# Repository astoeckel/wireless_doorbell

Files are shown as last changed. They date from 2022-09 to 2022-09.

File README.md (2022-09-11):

# Wireless Doorbell
**A hopelessly overengineered wireless doorbell transmitter (and Raspberry Pi AVR prototyping HAT)**

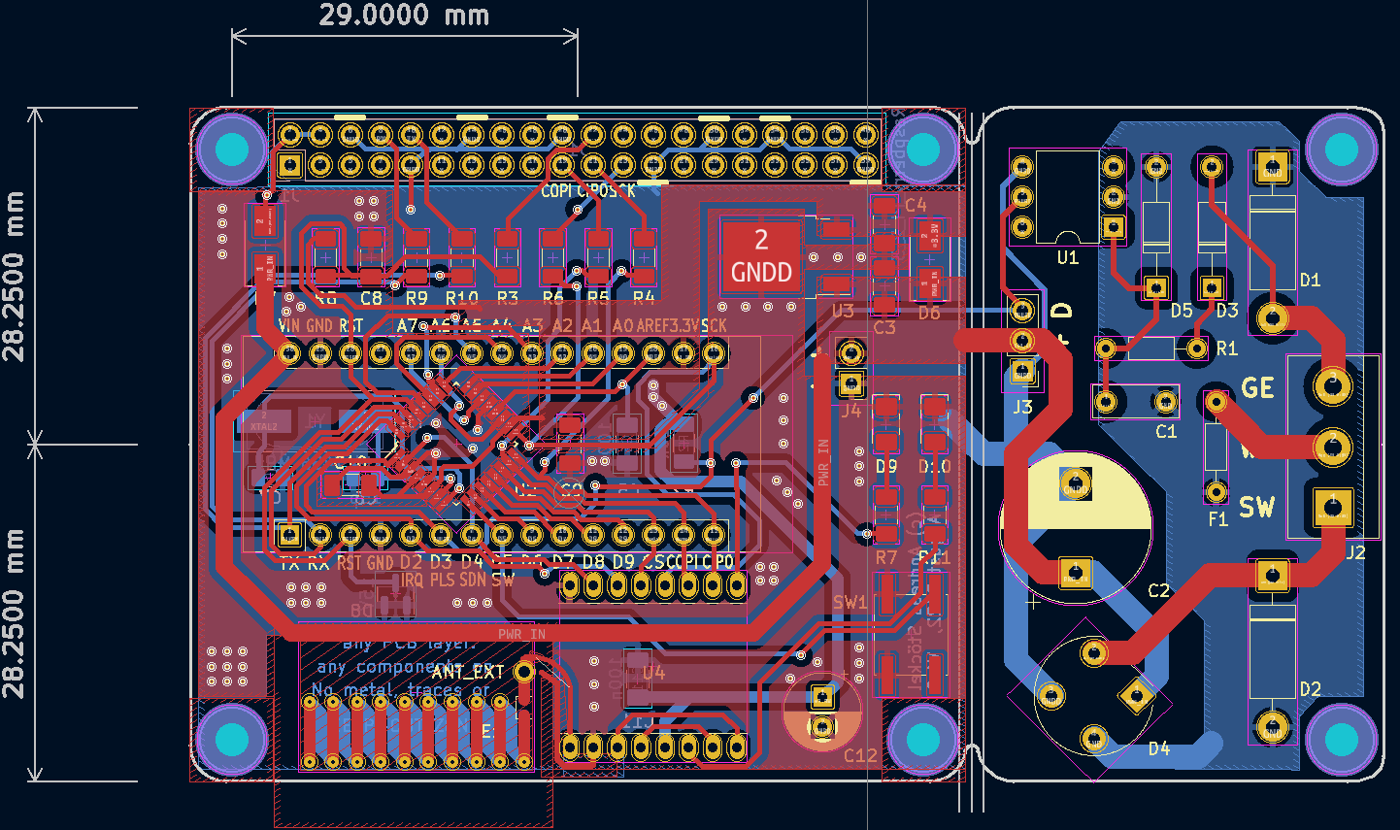
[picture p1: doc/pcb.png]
Screenshot of the PCB in KiCAD


> **Warning**  
> This project is provided as-is and likely not of use to anyone else; at least not without modifications. Note that:
> 1. The PCB (especially the AC supply) was designed for parts the author had lying around. Many of these parts may be obsolete.
> 2. This project solves a very niche problem.
> 3. The firmware uses plain-text wireless transmission without encryption or signatures. This is fine for the author's use case, where all an adversary can accomplish is to wirelessly ring the doorbell. A sneaky hacker could of course just press the doorbell button on the street to the same effect.
>
> **The author of this repository takes no responsibility for any damage resulting from using the electronic devices described here.**
> **You are responsible for making sure that operating these devices meets all relevant regulatory requirements in your region.**

This repository contains the PCB and firmware for a Si4463-based (on a HopeRF RFM26W module) wireless doorbell operating on the 433 MHz ISM band.
The Si4463 is controlled using an ATmega168 µC (the project requires about 6kiB of flash memory).

Doorbell button presses are transmitted wirelessly between two of these PCBs.
One of the PCBs serves as a Raspberry Pi HAT, where button press events are forwarded via UART to [OpenHAB](https://www.openhab.org/) (using [Serial Bridge and Serial Device](https://www.openhab.org/addons/bindings/serial/)).
In turn, OpenHAB has a rule that causes all SIP phones in the house to ring via [FemtoSIP](https://github.com/astoeckel/femtosip).

The left side of the PCB is a Raspberry Pi compatible AVR Microcontroller HAT (for the ATmega168/ATMega328 family) with Arduino-compatible pin headers and space for the HopeRF RFM26W module (note that this module seems to be obsolete).
The right side of the PCB is an low-voltage AC power supply with 50 Hz pulse extraction and is designed to be sawed off if not in use.

Since PCB prototyping services often produce at least 5-10 PCBs, the PCB was designed with some versatility in mind.
Correspondingly, the left side of the PCB has far more pin headers as necessary, and can be used as a general-purpose ATmega168/328 development board.
Specifically, the AVR can be programmed directly by the Raspberry Pi (no ISP programmer required) and can communicate via UART (the schematic suggests the use of a 14.7456 MHz crystal for stable high-speed communication).

## Overview

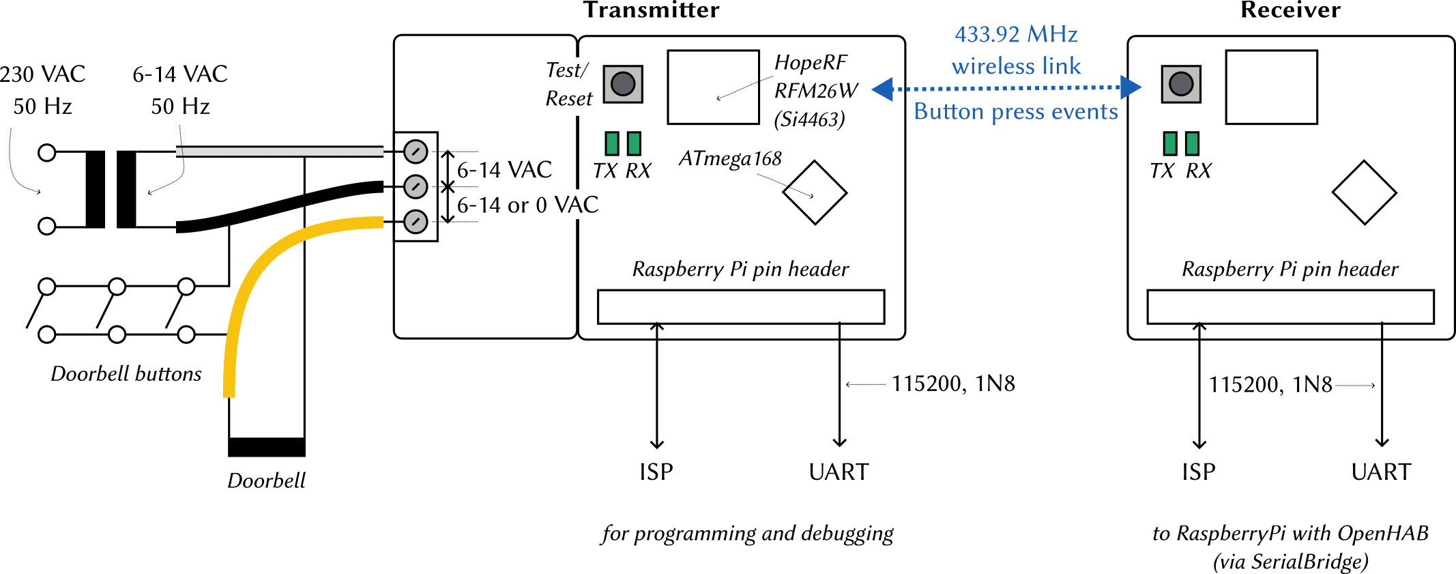
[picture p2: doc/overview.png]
Overview of the setup


The above diagram depicts how the PCB is intended to be used.
One instance of the PCB is directly powered by the low-voltage doorbell AC transformer; the other instance is powered by the 5V power supply of a Raspberry Pi.

Button presses are recognized by the doorbell button shorting out the yellow and black wires in the above diagram.
Correspondingly, the 50 Hz oscillations disappear on the yellow wire; this is recognized by the ATmega168 microcontroller which sends a few digital packets of the form
```
$DBG,<BUTTON PRESSED>,<SEQ>
```
to the receiver at a baud rate of 10kbps.
`<BUTTON PRESSED>` is set to `1` if the 50 Hz signal goes away; it is set to `0` once the signal reappears.
Every packet is repeated five times; with each repetition `<SEQ>` is incremented by one (starting from `0`).

## Schematics and Gerber files

* **Gerber files**  
  The Gerber files used for production can be found in the `gerber` folder (the author is not aware of any bugs on the PCB).
* **Schematic and KiCAD sources**  
  The KiCAD source files are in the `kicad` folder. A printout of the schematics in [PDF form](doc/schematics.pdf) can be found in the `doc` folder.

## Firmware

The firmware is located in the `code` folder.
It uses `avr-gcc` and `avr-libc`, as well as `avrdude` with the [linuxspi patches](https://github.com/kcuzner/avrdude).

It can be compiled and flashed using [meson](https://mesonbuild.com/) as follows:
```sh
cd code; mkdir -p build
meson setup --cross-file ../avr-unknown-gcc.txt ..
ninja
ninja flash  # Requires avrdude with linuxspi when flashing directly from the RPi
```

## Usage

The firmware automatically decides whether it acts as the receiver or transmitter depending on the presence of the 50 Hz pulse from the yellow wire in the above diagram.
Once a stable series of 50 Hz pulse are received, the device is in “transmitter” mode.

### Antenna
Note that the antenna on the board is designed for 868 MHz and does not have a large gain (close the solder bridge `J` on the board to activate the internal antenna).
In the final device, I'm using [this antenna](https://www.instructables.com/433-MHz-Coil-loaded-antenna/) ([PDF instructions by Ben Schueler](https://drive.google.com/file/d/1E9KPAPJrZRgGLOQqwd2-3-Px0MuSVreY/view)) soldered directly to the RFM26W module (the antenna is not connected to the PCB).

### Receiver

1. Connect UART RX/TX pins and 5V power (use a baud rate of 115200) to Raspberry Pi
2. The `RX` LED should be illuminated; the LED will blink rapidly if the receiver receives any data.
3. Incoming messages will be printed as a one-line JSON-encoded string to UART
4. Shortly pressing the SMD button on the board will send a `PING` request. If any board responds with a `PONG`, both the `RX` and `TX` LED will blink rapidly for two seconds. *Note:* The transmitter is usually in energy saving mode and will not respond. Wake the transmitter up by pressing the SMD button there.
5. Pressing the SMD button for at least 3 seconds will reset the µC on the board.

### Transmitter
1. Connect the three doorbell wires as indicated in the diagram above.
2. The `RX` led will blink once every second if the 50 Hz pulse has been recognized; the board will go to a 3-4mA power-save mode (this is to prevent the linear voltage regulator from becoming too hot).
3. If the 50 Hz signal goes away, the transmitter will send a message to the receiver as described above. The `TX` LED should blink rapidly.
4. Shortly pressing the SMD button will send a `PING` request and rapidly blink both LEDs if it receives a response. Furthermore, the transmitter will leave power-save mode for one minute; it can now respond with `PONG` to `PING` messages issued by the receiver.
5. Pressing the SMD button for 3 seconds will reset the µC on the board.

## License

Note that this project consists of both hardware and to a smaller portion of software. Both parts are made available under different licenses.

### Hardware schematics

    Copyright Andreas Stöckel 2022.
    
    This documentation describes Open Hardware and is licensed under the
    CERN OHL v. 1.2. You may redistribute and modify this documentation under
    the terms of the CERN OHL v.1.2. (http://ohwr.org/cernohl). This
    documentation is distributed WITHOUT ANY EXPRESS OR IMPLIED WARRANTY,
    INCLUDING OF MERCHANTABILITY, SATISFACTORY QUALITY AND FITNESS FOR A
    PARTICULAR PURPOSE. Please see the CERN OHL v.1.2 for applicable conditions.

### Software (AVR firmware and host programs)

    This program is free software: you can redistribute it and/or modify
    it under the terms of the GNU General Public License as published by
    the Free Software Foundation, either version 3 of the License, or
    (at your option) any later version.
    
    This program is distributed in the hope that it will be useful,
    but WITHOUT ANY WARRANTY; without even the implied warranty of
    MERCHANTABILITY or FITNESS FOR A PARTICULAR PURPOSE.  See the
    GNU General Public License for more details.
    
    You should have received a copy of the GNU General Public License
    along with this program.  If not, see <http://www.gnu.org/licenses/>.

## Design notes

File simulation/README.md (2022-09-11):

This directory contains some LTSpice simulations of different prototypes for the 14V AC power supply.
The final version in the `kicad` folder uses a simple bridge rectifier and a linear 3.3V regulator.

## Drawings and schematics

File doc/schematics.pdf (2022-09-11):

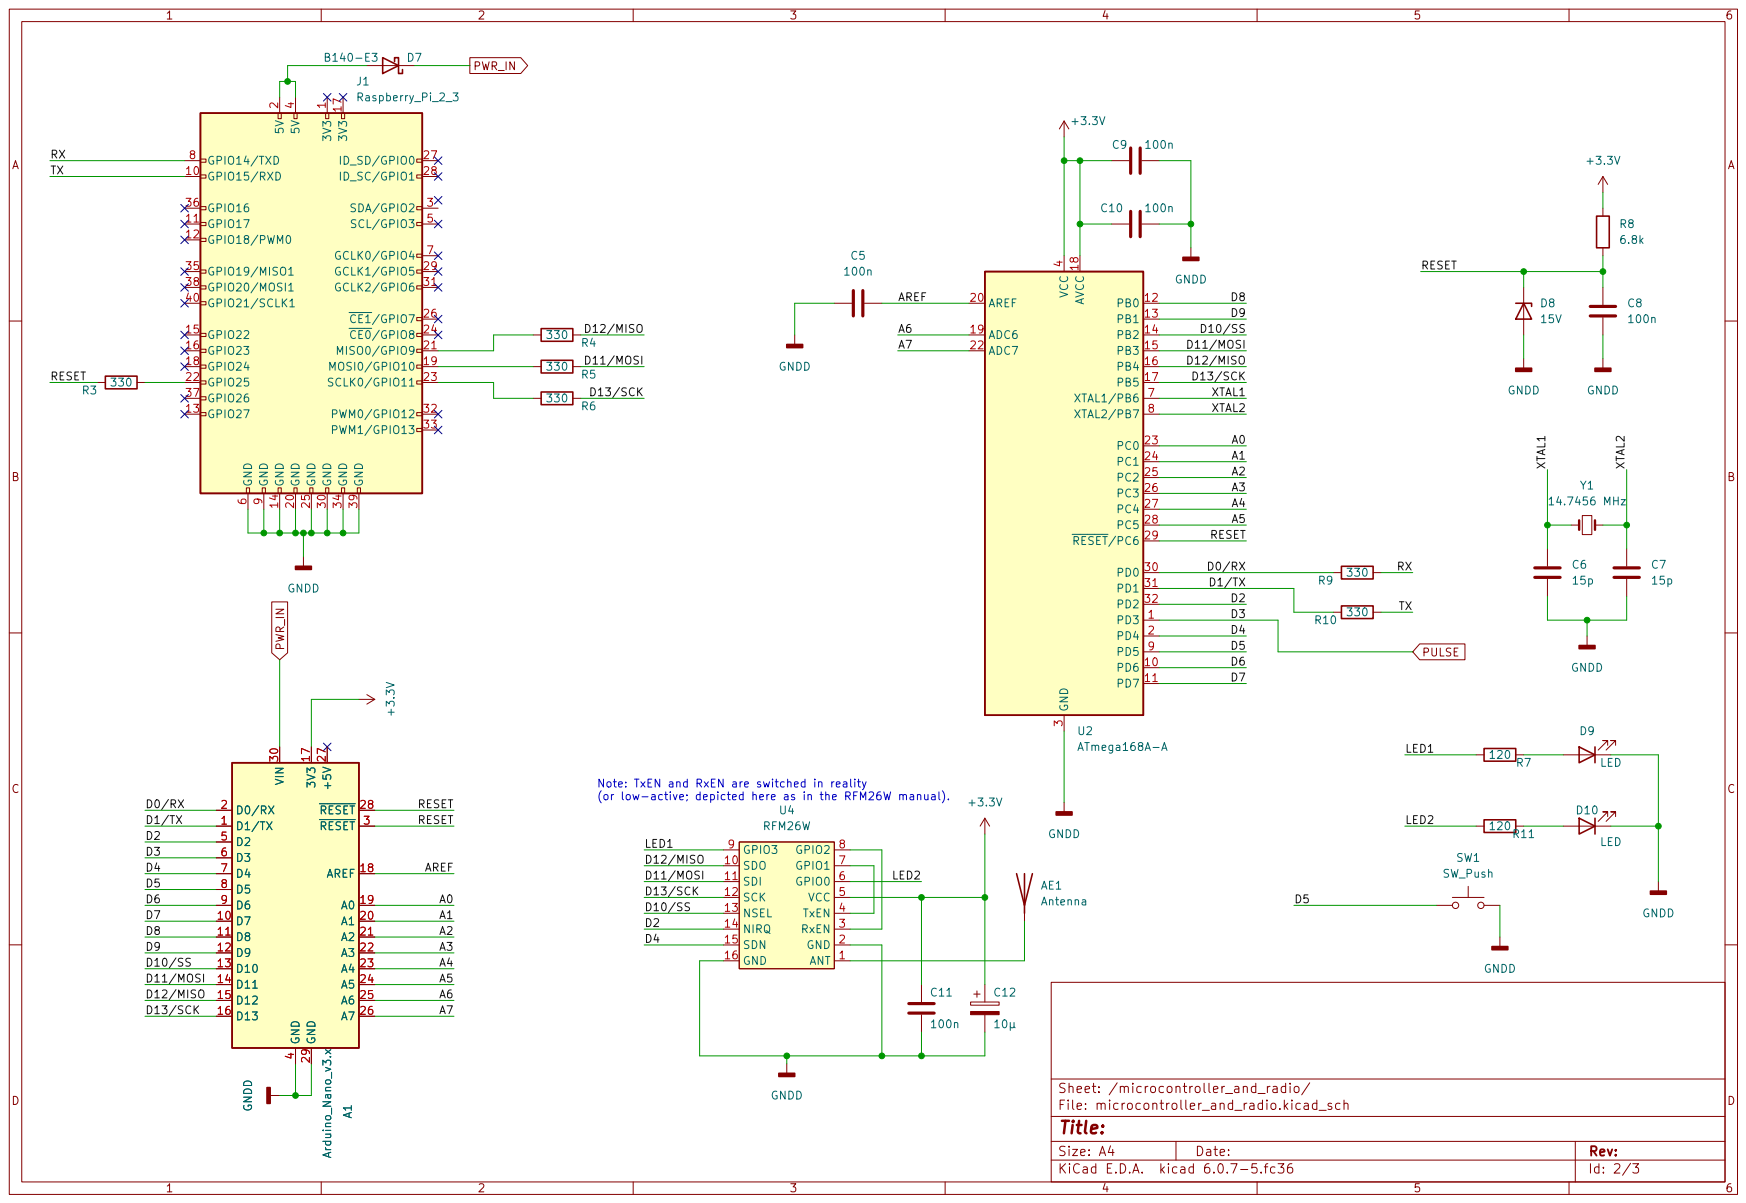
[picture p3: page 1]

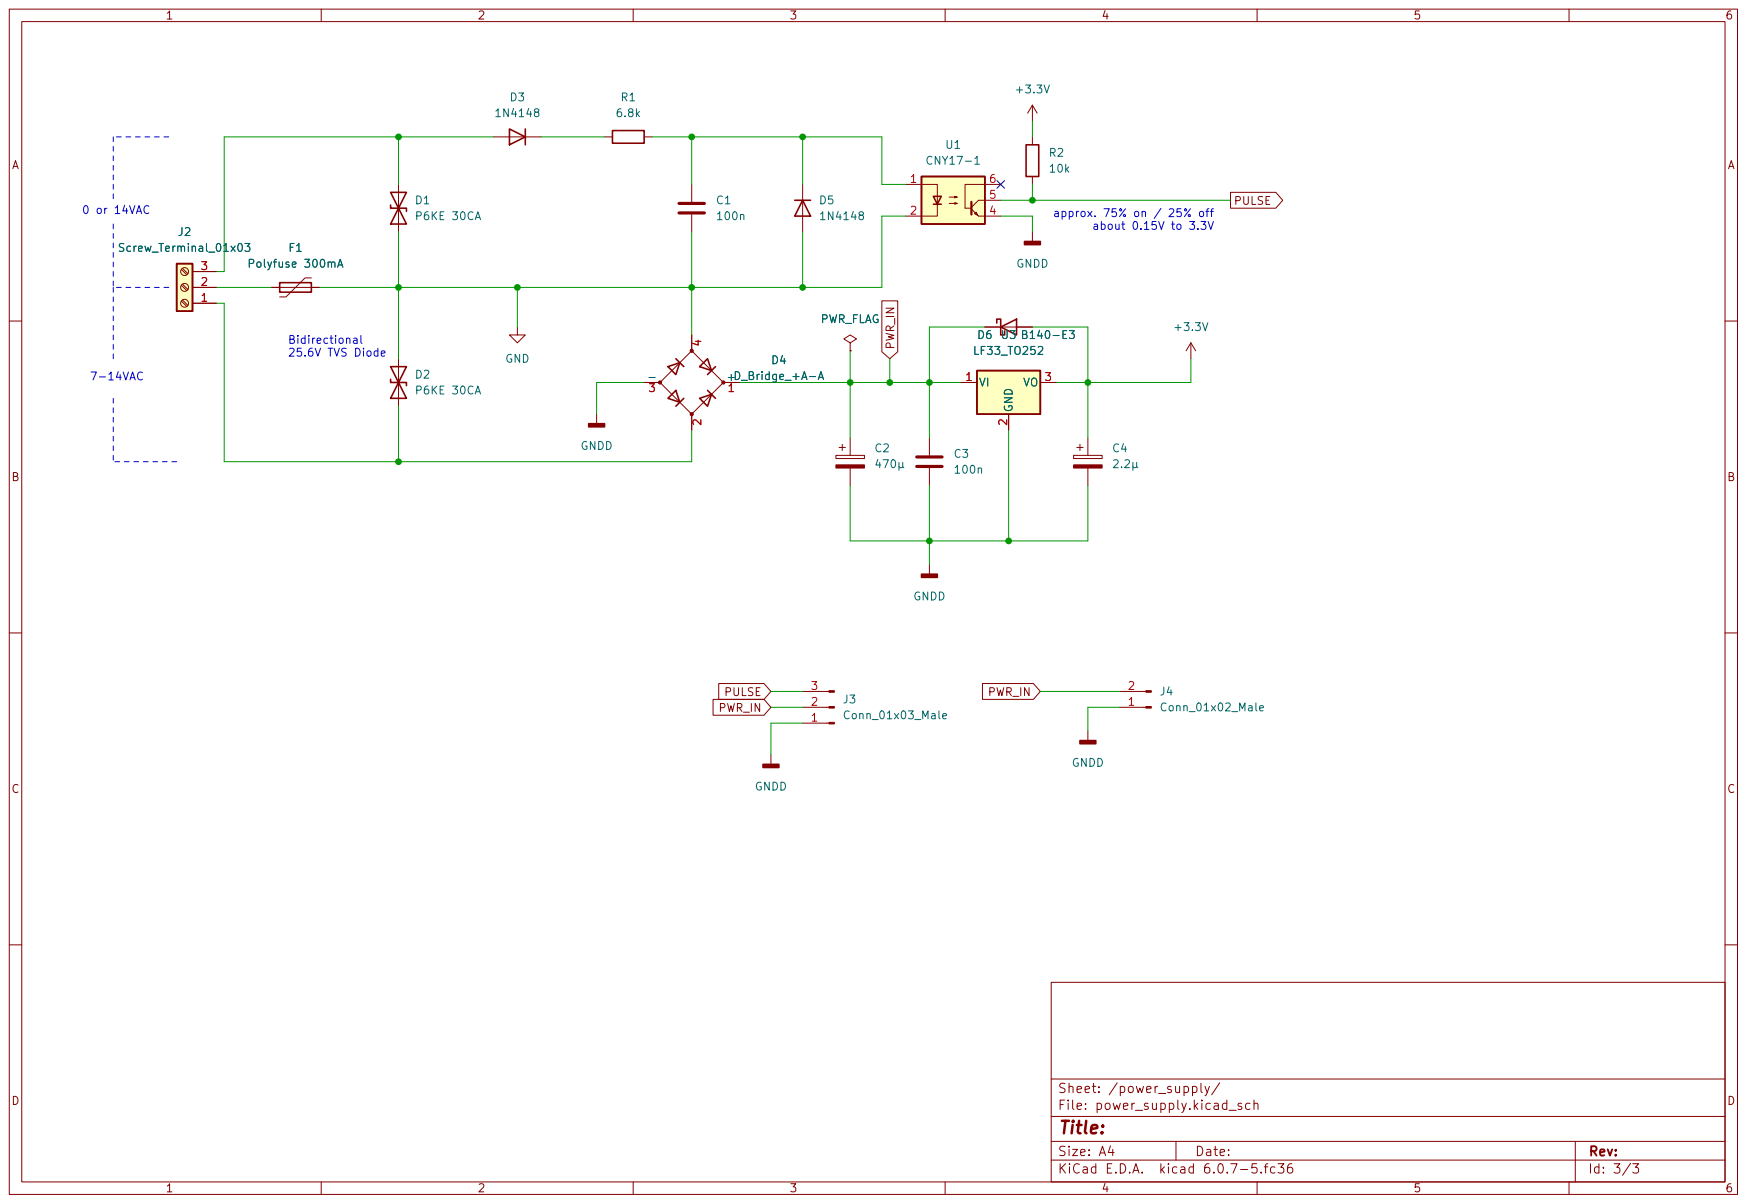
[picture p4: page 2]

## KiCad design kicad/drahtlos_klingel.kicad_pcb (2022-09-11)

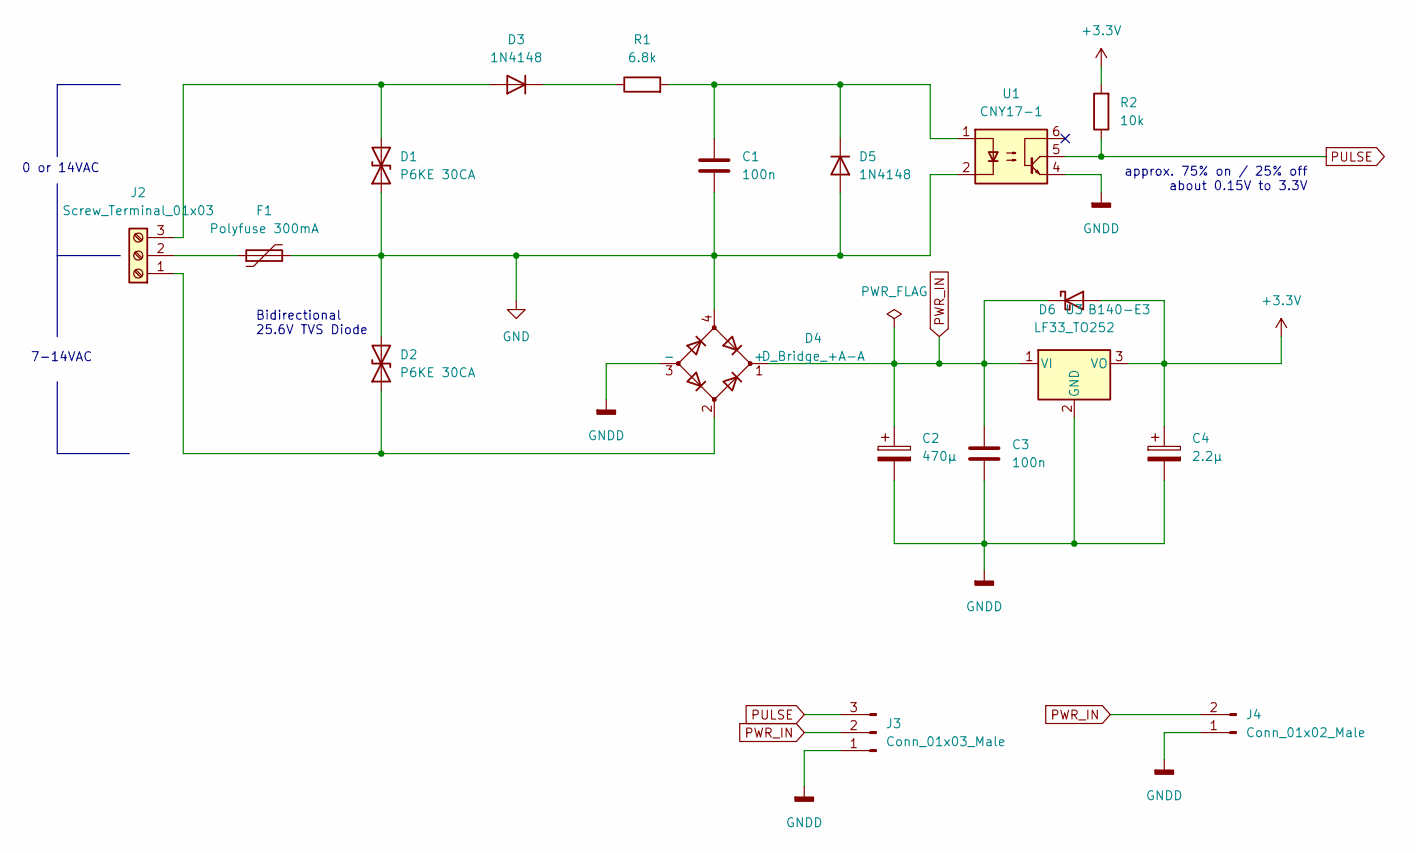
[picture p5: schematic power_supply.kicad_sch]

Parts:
C1: 100n; C_Rect_L7.0mm_W2.5mm_P5.00mm
C2: 470µ; CP_Radial_D12.5mm_P7.50mm
C3: 100n; C_1206_3216Metric_Pad1.33x1.80mm_HandSolder
C4: 2.2µ; C_1206_3216Metric_Pad1.33x1.80mm_HandSolder
D1, D2: P6KE 30CA; D_DO-15_P12.70mm_Horizontal
D3, D5: 1N4148; D_DO-35_SOD27_P10.16mm_Horizontal
D4: D_Bridge_+A-A; Diode_Bridge_Round_D9.8mm
D6: B140-E3; D_SMA
F1: Polyfuse 300mA; R_Axial_DIN0204_L3.6mm_D1.6mm_P7.62mm_Horizontal
J2: Screw_Terminal_01x03; TerminalBlock_bornier-3_P5.08mm
J3: Conn_01x03_Male; PinHeader_1x03_P2.54mm_Vertical
J4: Conn_01x02_Male; PinHeader_1x02_P2.54mm_Vertical
R1: 6.8k; R_Axial_DIN0204_L3.6mm_D1.6mm_P7.62mm_Horizontal
R2: 10k; R_1206_3216Metric_Pad1.30x1.75mm_HandSolder
U1: CNY17-1; DIP-6_W7.62mm
U3: LF33_TO252; TO-252-2

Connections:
+3.3V: C4.1, D6.2 (A), R2.2, U3.3 (VO); also elsewhere on the board
GND: C1.2, D1.1 (A1), D2.2 (A2), D4.4, D5.2 (A), F1.2, U1.2
GNDD: C2.2, C3.2, C4.2, D4.3 (-), J3.1, J4.1, U1.4, U3.2 (GND); also elsewhere on the board
unnamed: C1.1, D5.1 (K), R1.2, U1.1
unnamed: D1.2 (A2), D3.2 (A), J2.3
unnamed: D2.1 (A1), D4.2, J2.1
unnamed: D3.1 (K), R1.1
unnamed: F1.1, J2.2
PULSE: J3.3, R2.1, U1.5; also elsewhere on the board
PWR_IN: C2.1, C3.1, D4.1 (+), D6.1 (K), J3.2, J4.2, U3.1 (VI); also elsewhere on the board

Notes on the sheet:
0 or 14VAC
Bidirectional 25.6V TVS Diode
7-14VAC
approx. 75% on / 25% off about 0.15V to 3.3V

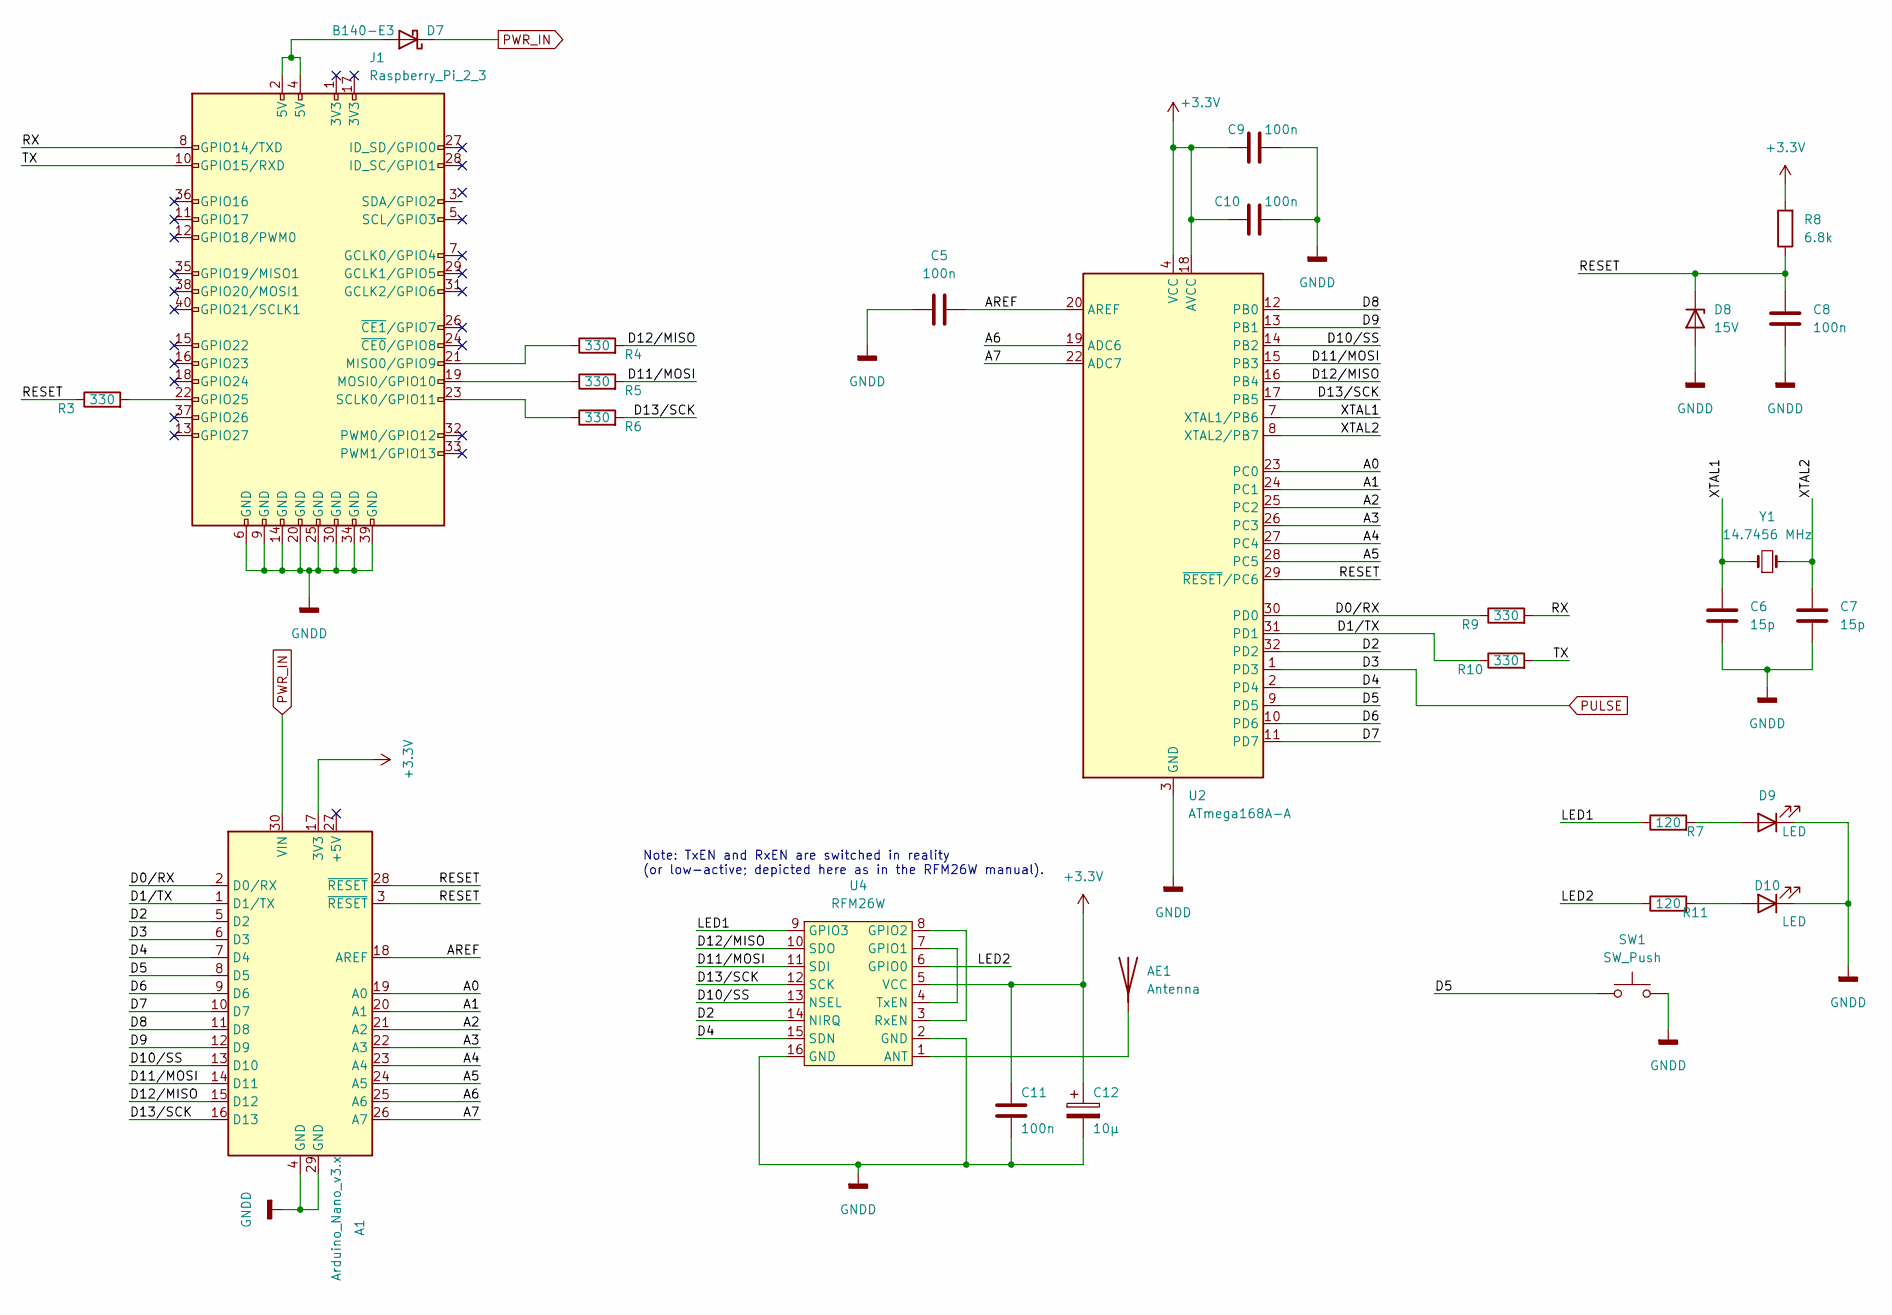
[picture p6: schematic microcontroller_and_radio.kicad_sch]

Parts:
A1: Arduino_Nano_v3.x; Arduino_Nano
AE1: Antenna; Texas_SWRA416_868MHz_915MHz
C5, C8, C9, C10, C11: 100n; C_1206_3216Metric_Pad1.33x1.80mm_HandSolder
C6, C7: 15p; C_0805_2012Metric_Pad1.18x1.45mm_HandSolder
C12: 10µ; CP_Radial_D6.3mm_P2.50mm
D7: B140-E3; D_SMA
D8: 15V; SOT-23
D9, D10: LED; LED_1206_3216Metric_Pad1.42x1.75mm_HandSolder
J1: Raspberry_Pi_2_3; PinSocket_2x20_P2.54mm_Vertical
R3, R4, R5, R6, R9, R10: 330; R_1206_3216Metric_Pad1.30x1.75mm_HandSolder
R7, R11: 120; R_1206_3216Metric_Pad1.30x1.75mm_HandSolder
R8: 6.8k; R_1206_3216Metric_Pad1.30x1.75mm_HandSolder
SW1: SW_Push; SW_SPST_EVQQ2
U2: ATmega168A-A; TQFP-32_7x7mm_P0.8mm
U4: RFM26W; rfm26w
Y1: 14.7456 MHz; Crystal_SMD_HC49-SD

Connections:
+3.3V: A1.17 (3V3), C9.1, C10.2, C11.1, C12.1, R8.2, U2.4 (VCC), U2.6 (VCC), U2.18 (AVCC), U4.5 (VCC); also elsewhere on the board
/microcontroller_and_radio/A0: A1.19 (A0), U2.23 (PC0)
/microcontroller_and_radio/A1: A1.20 (A1), U2.24 (PC1)
/microcontroller_and_radio/A2: A1.21 (A2), U2.25 (PC2)
/microcontroller_and_radio/A3: A1.22 (A3), U2.26 (PC3)
/microcontroller_and_radio/A4: A1.23 (A4), U2.27 (PC4)
/microcontroller_and_radio/A5: A1.24 (A5), U2.28 (PC5)
/microcontroller_and_radio/A6: A1.25 (A6), U2.19 (ADC6)
/microcontroller_and_radio/A7: A1.26 (A7), U2.22 (ADC7)
/microcontroller_and_radio/AREF: A1.18 (AREF), C5.2, U2.20 (AREF)
/microcontroller_and_radio/D0/RX: A1.2 (D0/RX), R9.1, U2.30 (PD0)
/microcontroller_and_radio/D1/TX: A1.1 (D1/TX), R10.1, U2.31 (PD1)
/microcontroller_and_radio/D2: A1.5 (D2), U2.32 (PD2), U4.14 (NIRQ)
/microcontroller_and_radio/D4: A1.7 (D4), U2.2 (PD4), U4.15 (SDN)
/microcontroller_and_radio/D5: A1.8 (D5), SW1.1, U2.9 (PD5)
/microcontroller_and_radio/D6: A1.9 (D6), U2.10 (PD6)
/microcontroller_and_radio/D7: A1.10 (D7), U2.11 (PD7)
/microcontroller_and_radio/D8: A1.11 (D8), U2.12 (PB0)
/microcontroller_and_radio/D9: A1.12 (D9), U2.13 (PB1)
/microcontroller_and_radio/D10/SS: A1.13 (D10), U2.14 (PB2), U4.13 (NSEL)
/microcontroller_and_radio/D11/MOSI: A1.14 (D11), R5.2, U2.15 (PB3), U4.11 (SDI)
/microcontroller_and_radio/D12/MISO: A1.15 (D12), R4.2, U2.16 (PB4), U4.10 (SDO)
/microcontroller_and_radio/D13/SCK: A1.16 (D13), R6.2, U2.17 (PB5), U4.12 (SCK)
/microcontroller_and_radio/LED1: R7.1, U4.9 (GPIO3)
/microcontroller_and_radio/LED2: R11.1, U4.6 (GPIO0)
/microcontroller_and_radio/RESET: A1.3 (~RESET), A1.28 (~RESET), C8.1, D8.1 (K), R3.1, R8.1, U2.29 (~RESET/PC6)
/microcontroller_and_radio/RX: J1.8 (GPIO14/TXD), R9.2
/microcontroller_and_radio/TX: J1.10 (GPIO15/RXD), R10.2
/microcontroller_and_radio/XTAL1: C6.1, U2.7 (XTAL1/PB6), Y1.1
/microcontroller_and_radio/XTAL2: C7.1, U2.8 (XTAL2/PB7), Y1.2
GNDD: A1.4 (GND), A1.29 (GND), C5.1, C6.2, C7.2, C8.2, C9.2, C10.1, C11.2, C12.2, D8.2 (A), D9.1 (K), D10.1 (K), J1.6 (GND), J1.9 (GND), J1.14 (GND), J1.20 (GND), J1.25 (GND), J1.30 (GND), J1.34 (GND), J1.39 (GND), SW1.2, U2.3 (GND), U2.5 (GND), U2.21 (GND), U4.2 (GND), U4.16 (GND); also elsewhere on the board
unnamed: AE1.1 (A), U4.1 (ANT)
unnamed: D7.2 (A), J1.2 (5V), J1.4 (5V)
unnamed: D9.2 (A), R7.2
unnamed: D10.2 (A), R11.2
unnamed: J1.19 (MOSI0/GPIO10), R5.1
unnamed: J1.21 (MISO0/GPIO9), R4.1
unnamed: J1.22 (GPIO25), R3.2
unnamed: J1.23 (SCLK0/GPIO11), R6.1
unnamed: U4.3 (RxEN), U4.8 (GPIO2)
unnamed: U4.4 (TxEN), U4.7 (GPIO1)
PULSE: A1.6 (D3), U2.1 (PD3); also elsewhere on the board
PWR_IN: A1.30 (VIN), D7.1 (K); also elsewhere on the board

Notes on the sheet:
Note: TxEN and RxEN are switched in reality (or low-active; depicted here as in the RFM26W manual).

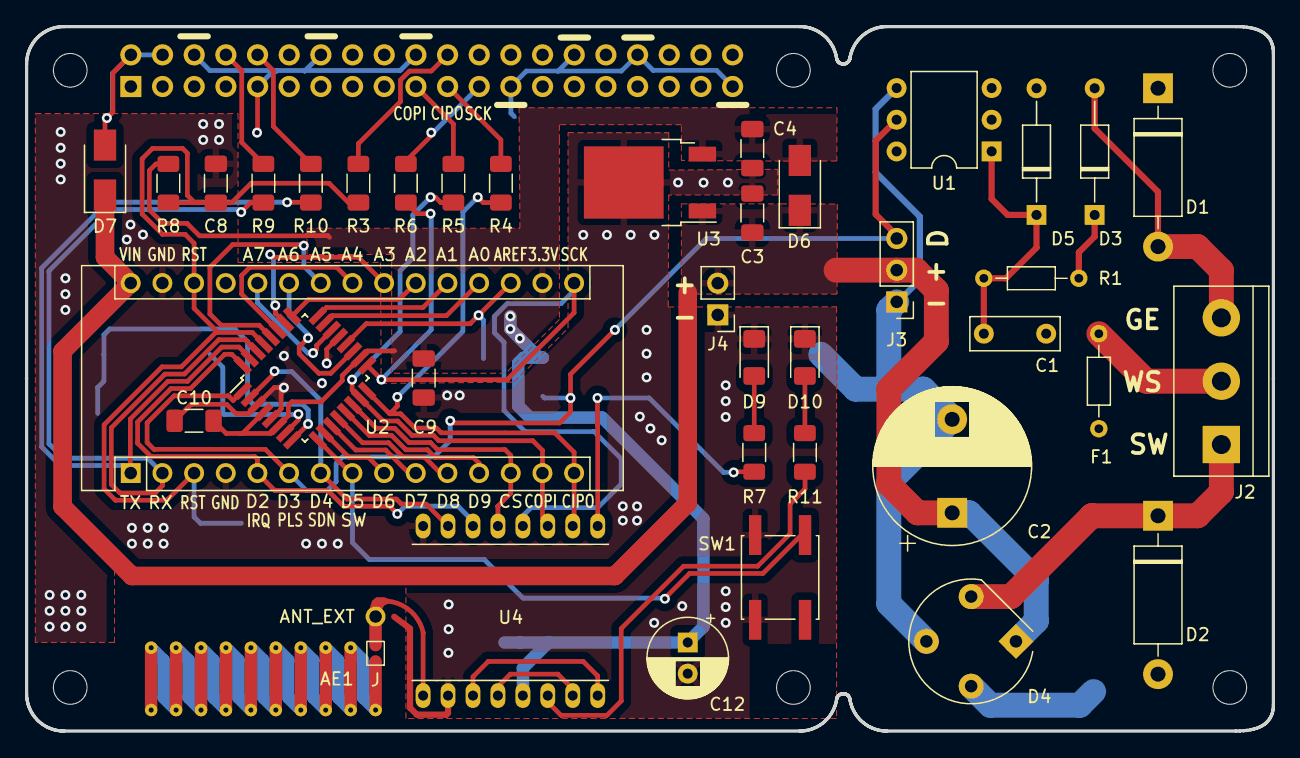
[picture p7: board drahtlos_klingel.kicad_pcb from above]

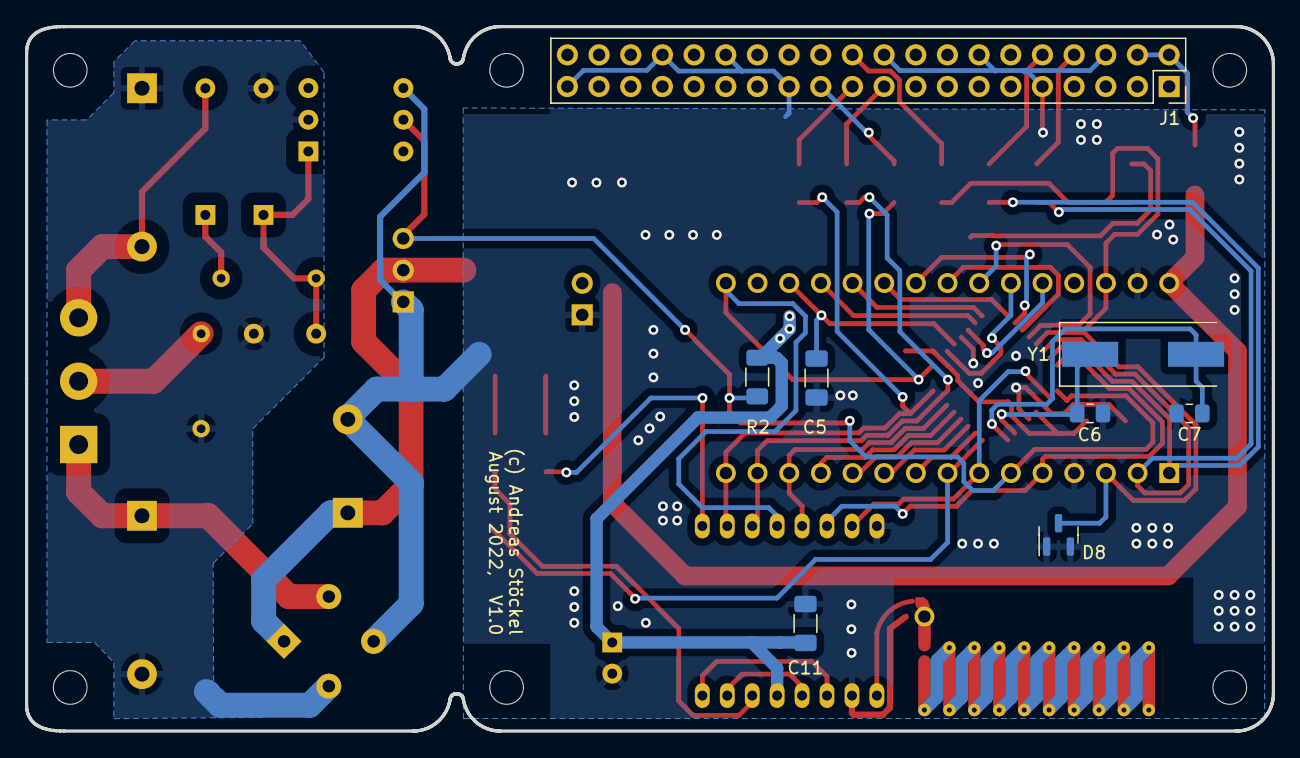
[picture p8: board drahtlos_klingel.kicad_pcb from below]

Board: 2 copper layers, 100.0 x 56.5 mm, 46 parts (8 on the bottom side), 49 nets.

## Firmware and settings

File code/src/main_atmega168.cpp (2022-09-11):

/*
 *  AVR/Si4463 Wireless Doorbell
 *  Copyright (C) 2022  Andreas Stöckel
 *
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
 *  You should have received a copy of the GNU General Public License
 *  along with this program.  If not, see <https://www.gnu.org/licenses/>.
 */

#include <platform.hpp>
#include <si4463.hpp>
#include <uart.hpp>

#include <avr/interrupt.h>
#include <avr/io.h>
#include <avr/pgmspace.h>
#include <avr/sleep.h>
#include <avr/wdt.h>
#include <stddef.h>
#include <stdint.h>
#include <util/atomic.h>
#include <util/delay.h>

#include <utils/buffer.hpp>
#include <utils/byte_suffix.hpp>

#include "platform.hpp"

/******************************************************************************
 * Watchdog timer                                                             *
 ******************************************************************************/

namespace Watchdog {
static inline void disable()
{
	MCUSR = 0;
	wdt_disable();
}

static inline void reset() { wdt_reset(); }

static inline void enable() { wdt_enable(WDTO_120MS); }

}  // namespace Watchdog

/******************************************************************************
 * 100µs clock                                                                *
 ******************************************************************************/

namespace Clock {

static uint8_t _increment;
static uint16_t _ticks;

ISR(TIMER1_COMPA_vect)
{
	_ticks += _increment;  // Increment the 100µs tick counter
}

static inline void init()
{
	// Reset the timer configuration; disable PWM output and waveform generation
	TCCR1A = 0_B;
	TCCR1B = 0_B;
	TCCR1C = 0_B;
	TIMSK1 = 0_B;
	TCNT1 = 0;
	_ticks = 0;
	_increment = 1;

	// Generate an interrupt approximately every 100µs; operate the
	// counter in CTC mode
	OCR1A = (F_CPU / 10000);              // compare value
	TIMSK1 = (1 << OCIE1A);               // enable compare interrupt
	TCCR1B = (1 << WGM12) | (1 << CS10);  // CTC mode, highest possible speed
}

static inline void go_slow()
{
	// Generate an interrupt approximately every 2ms
	_increment = 10;
	TCNT1 = 0;
	OCR1A = (F_CPU / 1000);  // compare value
}

static inline void go_fast()
{
	// Generate an interrupt approximately every 100µs
	_increment = 1;
	TCNT1 = 0;
	OCR1A = (F_CPU / 10000);  // compare value
}

static inline uint16_t ticks()
{
	ATOMIC_BLOCK(ATOMIC_RESTORESTATE) { return _ticks; }
	__builtin_unreachable();
}

};  // namespace Clock

/******************************************************************************
 * Interrupts                                                                 *
 ******************************************************************************/

namespace Events {
struct Event {
	bool valid;
	uint16_t time;

	operator bool() const { return valid; }
};

Event pulse, radio_irq;

void init()
{
	pulse = Event{.valid = false, .time = 0};
	radio_irq = Event{.valid = false, .time = 0};
}

Event get_and_reset_pulse_event()
{
	ATOMIC_BLOCK(ATOMIC_RESTORESTATE)
	{
		Event res = pulse;
		pulse.valid = false;
		return res;
	}
	__builtin_unreachable();
}

Event get_and_reset_radio_irq_event()
{
	ATOMIC_BLOCK(ATOMIC_RESTORESTATE)
	{
		Event res = radio_irq;
		radio_irq.valid = false;
		return res;
	}
	__builtin_unreachable();
}

ISR(INT0_vect)
{
	if (!Platform::sample_radio_irq_pin()) {
		radio_irq = Event{.valid = true, .time = Clock::ticks()};
	}
}

ISR(INT1_vect)
{
	if (!Platform::sample_pulse_pin()) {
		pulse = Event{.valid = true, .time = Clock::ticks()};
	}
}
};  // namespace Events

namespace Sleep {
void init()
{
	set_sleep_mode(SLEEP_MODE_IDLE);  // Lowest possible sleep mode where the
	                                  // timer still runs
}

void enter()
{
	sleep_enable();
	sei();
	sleep_cpu();
	sleep_disable();
}

}  // namespace Sleep

/******************************************************************************
 * MAIN PROGRAM                                                               *
 ******************************************************************************/

/**
 * The `DoorbellButtonStateMachine` is responsible for detecting doorbell button
 * presses.
 *
 * If the doorbell button is depressed, there should be a periodic 50 Hz signal
 * at PIND3; the timing of this signal is precisely captured by the interrupt
 * code above.
 *
 * If the doorbell button is pressed, this periodic signal will go away. This
 * code makes sure that a doorbell button-press event is only triggered if
 *
 *    1. There was a periodic 50-60 Hz signal before the signal went away.
 *    2. The signal goes away for a minimum delay.
 *    3. The corresponding hardware pin is actually high when after the minimum
 *       delay.
 *
 * This is meant to minimize false-positive doorbell triggers.
 */
struct DoorbellButton {
	enum State {
		Unknown,
		Pressed,
		Depressed,
	};

	static constexpr uint16_t MIN_DELTA = 126;      // 1 / 60 Hz - 4ms
	static constexpr uint16_t MAX_DELTA = 240;      // 1 / 50 Hz + 4ms
	static constexpr uint16_t DEPRESS_DELAY = 800;  // 80 ms (4 cycles @ 50 Hz)
	static constexpr uint8_t AC_CARRIER_SYNC = 5;   // 5 cycles to synchronise

	uint8_t ac_carrier_pulse_count = 0;
	uint16_t last_falling_edge_ticks = 0;

	State update(uint16_t cur_ticks, const Events::Event &pulse_event,
	             bool pin_state)
	{
		// Check whether the delay between the last detected pulse and the
		// current pulse is larger than 65ms (> 3 cycles). If we are locked
		// (i.e., we detected many valid 50/60 Hz pulses previously), then this
		// should mean that the doorbell button was pressed.
		const uint16_t delta = cur_ticks - last_falling_edge_ticks;
		if ((delta > DEPRESS_DELAY) &&
		    (ac_carrier_pulse_count >= AC_CARRIER_SYNC)) {
			// We were synchronised. Someone must have rang the doorbell!
			ac_carrier_pulse_count = 0;

			// Reset last_falling_edge_ticks to prevent overflows of delta
			last_falling_edge_ticks = cur_ticks;

			// Is the pulse pin still high? If not, we might just be running
			// out of power.
			if (pin_state) {
				return Pressed;
			}
		}
		else if (pulse_event) {
			const uint16_t delta = pulse_event.time - last_falling_edge_ticks;
			last_falling_edge_ticks = pulse_event.time;

			// Were the falling edges 50 or 60 Hz apart? If we get at least 10
			// such pulses, we count that as synchronised.
			if (delta >= MIN_DELTA && delta <= MAX_DELTA) {
				if (ac_carrier_pulse_count < AC_CARRIER_SYNC) {
					ac_carrier_pulse_count++;
				}
			}
			else {
				// Something weird happened, we are no longer synchronised
				ac_carrier_pulse_count = 0;
			}
		}
		return (ac_carrier_pulse_count >= AC_CARRIER_SYNC) ? Depressed
		                                                   : Unknown;
	}

	bool can_sleep() { return ac_carrier_pulse_count == AC_CARRIER_SYNC; }
};

struct DebouncedIO {
	/**
	 * Time for which the I/O pin needs to be stable.
	 */
	static constexpr uint16_t DEBOUNCE_TICKS = 500;  // 50ms

	bool cur_state = true;
	bool last_raw_in = false;
	uint16_t last_edge_ticks = 0;

	bool update(uint16_t cur_ticks, bool raw_in)
	{
		if (raw_in != last_raw_in) {
			last_raw_in = raw_in;
			last_edge_ticks = cur_ticks;
		}
		if (cur_ticks - last_edge_ticks >= DEBOUNCE_TICKS) {
			last_edge_ticks = cur_ticks - DEBOUNCE_TICKS;
			cur_state = raw_in;
		}
		return cur_state;
	}

	bool can_sleep(uint16_t cur_ticks)
	{
		return (cur_ticks - last_edge_ticks) >= DEBOUNCE_TICKS;
	}
};

struct OnboardButton {
	/**
	 * Number of seconds the button has to be pushed down for the board to
	 * reset.
	 */
	static constexpr uint8_t RESET_DUR_SEC = 3;  // 3s

	/**
	 * Number of seconds for which pressing the button forces non-power-save
	 * mode.
	 */
	static constexpr uint8_t NO_SLEEP_DUR_SEC = 60;  // 60s

	enum Action {
		DoNothing,
		SendPing,
		Reset,
	};

	uint16_t last_button_press_sec_ticks = 0;
	uint8_t no_sleep_secs = 0;
	uint8_t reset_secs = 0;
	bool last_is_pressed = false;

	Action update(uint16_t cur_ticks, bool pin_state)
	{
		// Fetch the actual button state (high = depressed, low = pressed)
		const bool is_pressed = !pin_state;

		if (is_pressed != last_is_pressed) {
			last_is_pressed = is_pressed;
			last_button_press_sec_ticks = cur_ticks;
			if (is_pressed) {
				no_sleep_secs = NO_SLEEP_DUR_SEC;
				reset_secs = RESET_DUR_SEC;
				return Action::SendPing;
			}
			else {
				reset_secs = 0;
			}
		}

		// Count the number of seconds since the last button press
		uint16_t delta_sec = cur_ticks - last_button_press_sec_ticks;
		if (delta_sec > 10000) {
			last_button_press_sec_ticks += 10000;
			if (no_sleep_secs > 0) {
				no_sleep_secs--;
			}
			if (last_is_pressed && reset_secs > 0) {
				reset_secs--;
				if (reset_secs == 0) {
					return Action::Reset;
				}
			}
		}

		return Action::DoNothing;
	}

	bool can_sleep() { return !last_is_pressed && (no_sleep_secs == 0); }
};

struct DoorbellButtonTxStateMachine {
	static constexpr uint8_t FORCE_IVAL_SEC = 120;
	static constexpr uint8_t FORCE_IVAL_SEC_UNKNOWN = 10;
	static constexpr uint16_t REPEAT = 5;
	static constexpr uint16_t IVAL_MS = 500;  // 50 ms

	DoorbellButton::State last_doorbell_state = DoorbellButton::Unknown;
	uint8_t tx_doorbell_seq_idx = 0;
	bool tx_doorbell_forced = false;
	bool had_good_state_once = false;
	uint16_t tx_doorbell_event_ticks = 0;
	uint8_t last_tx_seconds = FORCE_IVAL_SEC;
	uint16_t last_seconds_ticks = 0;

	template <typename T>
	void update(uint16_t cur_ticks, DoorbellButton::State button_state,
	            T &radio_tx_buf)
	{
		// Second counter; force an update every FORCE_IVAL_SEC seconds.
		if ((cur_ticks - last_seconds_ticks > 10000) && had_good_state_once) {
			last_tx_seconds++;
			last_seconds_ticks += 10000;
			if (((button_state == DoorbellButton::Unknown) &&
			     (last_tx_seconds > FORCE_IVAL_SEC_UNKNOWN)) ||
			    (last_tx_seconds > FORCE_IVAL_SEC)) {
				tx_doorbell_seq_idx = REPEAT;
				tx_doorbell_forced = true;
				last_tx_seconds = 0;
			}
		}

		// If there was a transition in button state, print a message and
		// update the output
		if ((button_state != DoorbellButton::Unknown) &&
		    (button_state != last_doorbell_state)) {
			had_good_state_once = true;
			last_doorbell_state = button_state;
			switch (button_state) {
				case DoorbellButton::Pressed:
					UART::print_json_msg("info", "doorbell button pressed");
					tx_doorbell_seq_idx = 2 * REPEAT;
					tx_doorbell_event_ticks = cur_ticks - IVAL_MS;
					tx_doorbell_forced = false;
					break;
				case DoorbellButton::Depressed:
					UART::print_json_msg("info", "doorbell button depressed");
					if (tx_doorbell_seq_idx < REPEAT) {
						tx_doorbell_seq_idx = REPEAT;
						tx_doorbell_forced = false;
					}
					break;
				default:
					break;
			}
		}

		// Transmit any outstanding the doorbell events
		if (tx_doorbell_seq_idx &&
		    (cur_ticks - tx_doorbell_event_ticks) >= IVAL_MS) {
			tx_doorbell_event_ticks = cur_ticks;

			bool is_on = (tx_doorbell_seq_idx > REPEAT);
			bool is_off = (last_doorbell_state == DoorbellButton::Depressed) ||
			              (tx_doorbell_forced);
			if (is_on || is_off) {
				uint8_t seq = (is_on ? 2 : 1) * REPEAT - tx_doorbell_seq_idx;
				radio_tx_buf.push("$DBL,");
				if (is_on) {
					radio_tx_buf.push('1');
				}
				else {
					if (tx_doorbell_forced &&
					    (button_state == DoorbellButton::Unknown)) {
						radio_tx_buf.push('?');
					}
					else {
						radio_tx_buf.push('0');
					}
				}
				radio_tx_buf.push(',');
				radio_tx_buf.push('0' + seq);
				radio_tx_buf.push("\r\n");
				tx_doorbell_seq_idx--;
				last_tx_seconds = 0;
			}
		}
	}

	bool can_sleep() { return tx_doorbell_seq_idx == 0; }
};

/**
 * The `RadioStateMachine` class is responsible for transitioning the
 * wireless transceiver IC into the right state, sending the bytes stored
 * in the transmit buffer, and writing received bytes to a receive buffer.
 */
struct RadioStateMachine {
	uint16_t first_radio_tx_ticks = 0;
	bool has_radio_tx = false;
	Si4463::State known_state = Si4463::State::Sleep;
	Si4463::State target_state = Si4463::State::Ready;

	template <typename T1, typename T2>
	void update(uint16_t cur_ticks, T1 &radio_rx_buf, T2 &radio_tx_buf,
	            bool can_sleep)
	{
		// Is there data in the transmit buffer? If yes, either wait for
		// 20ms or until the buffer is half full
		const uint8_t radio_tx_level = radio_tx_buf.level();
		if (radio_tx_level && !has_radio_tx) {
			first_radio_tx_ticks = cur_ticks;
			has_radio_tx = true;
		}
		bool need_tx =
		    radio_tx_level && ((radio_tx_level >= radio_tx_buf.size() / 2) ||
		                       ((cur_ticks - first_radio_tx_ticks) > 400));

		if (known_state != target_state) {
			known_state = Si4463::get_state();
		}
		if (known_state == Si4463::State::Ready) {
			if (need_tx) {
				const uint8_t n_send =
				    (radio_tx_level > 63) ? 63 : radio_tx_level;
				const uint8_t p1 = radio_tx_buf.read_ptr;
				const uint8_t p2 = (radio_tx_buf.read_ptr + n_send) &
				                   (radio_tx_buf.size() - 1);
				if (p1 < p2) {
					Si4463::write_tx_fifo(
					    n_send, Buffer(radio_tx_buf.data + p1, n_send));
				}
				else {
					Si4463::write_tx_fifo(n_send,
					                      Buffer(radio_tx_buf.data + p1,
					                             radio_tx_buf.size() - p1),
					                      Buffer(radio_tx_buf.data, p2));
				}
				radio_tx_buf.read_ptr = p2;

				// Set the packet length
				Si4463::set_pkt_len(n_send);

				// Start the transmission; wait until we're in the ready state
				Si4463::start_tx(0);
				known_state = Si4463::State::Tx;
				target_state = Si4463::State::Ready;

				// Reset the maximum packet length for the receiver
				Si4463::set_pkt_len(63);

				// Determine whether we still have data in the send buffer
				has_radio_tx = (n_send != radio_tx_level);
			}
			else if (!can_sleep) {
				// If we don't need to transmit something, go to the RX mode
				Si4463::start_rx(0);
				target_state = Si4463::State::Rx;
			}
		}
		else if (known_state == Si4463::State::Rx) {
			// Put all the received data into the RX buffer
			const uint8_t radio_rx_level = radio_rx_buf.level();
			const uint8_t rx_count = Si4463::rx_fifo_count();
			const uint8_t rx_space = radio_rx_buf.size() - radio_rx_level;
			const uint8_t n_recv = (rx_count < rx_space) ? rx_count : rx_space;
			if (n_recv) {
				const uint8_t p1 = radio_rx_buf.write_ptr;
				const uint8_t p2 = (radio_rx_buf.write_ptr + n_recv) &
				                   (radio_rx_buf.size() - 1);
				if (p1 < p2) {
					Si4463::read_rx_fifo(
					    Buffer(radio_rx_buf.data + p1, n_recv));
				}
				else {
					Si4463::read_rx_fifo(Buffer(radio_rx_buf.data + p1,
					                            radio_rx_buf.size() - p1),
					                     Buffer(radio_rx_buf.data, p2));
				}
				radio_rx_buf.write_ptr = p2;
			}

			if (!rx_count && (need_tx || can_sleep) &&
			    (Si4463::get_rssi() < 0x30)) {
				Si4463::set_state(Si4463::State::Ready);
				target_state = Si4463::State::Ready;
				known_state = Si4463::State::Ready;
			}
		}
	}

	bool can_sleep() { return !has_radio_tx && (known_state == target_state); }
};

struct LEDStateMachine {
	enum State {
		Off,
		On,
		BlinkSlowlyOn,
		BlinkSlowlyOff,
		BlinkQuickly,
	};

	uint16_t last_led_ticks = 0;
	State event_state = State::Off;
	State base_state = State::Off;
	uint8_t led_phase = 0;
	uint8_t event_len = 0;
	bool is_on = false;

	bool update(uint16_t cur_ticks)
	{
		if (cur_ticks - last_led_ticks > 1000) {
			last_led_ticks += 1000;
			led_phase++;
			if (led_phase == 10) {
				led_phase = 0;
			}
			if (event_len > 0) {
				event_len--;
			}
			State state = event_len ? event_state : base_state;
			switch (state) {
				case State::Off:
					is_on = false;
					break;
				case State::On:
					is_on = true;
					break;
				case State::BlinkSlowlyOff:
					is_on = (led_phase == 9);
					break;
				case State::BlinkSlowlyOn:
					is_on = (led_phase != 9);
					break;
				case State::BlinkQuickly:
					is_on = (led_phase & 1) == 0;
					break;
			}
		}
		return is_on;
	}

	void set_state(State new_state, uint8_t new_event_len = 0)
	{
		if (new_event_len) {
			if ((new_event_len > event_len) || (new_state != event_state)) {
				event_state = new_state;
				event_len = new_event_len;
			}
		}
		else {
			base_state = new_state;
		}
	}

	bool can_sleep() { return event_len == 0; }
};
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
int main()
{
	bool last_can_sleep = false;

	DebouncedIO btn_onboard_debounce;
	OnboardButton btn_onboard;
	DoorbellButton btn_doorbell;
	DoorbellButtonTxStateMachine doorbell_tx;
	RadioLEDStateMachine radio_leds;

	char pkt_msg[16];
	uint8_t pkt_ptr = 0;

	RadioStateMachine radio;
	Ringbuffer<32> radio_tx_buf;
	Ringbuffer<32> radio_rx_buf;

	// Reset the watchdog
	Watchdog::disable();
	Sleep::init();

	Platform::init_gpio();
	Watchdog::enable();
	Events::init();
	Clock::init();
	UART::init();

	Si4463::reset();
	Si4463::init();
	UART::print_json_msg("info", "power on reset");
	if (Si4463::part_number() != 0x4463) {
		UART::print_json_msg("error", "unknown part");
		while (true) {}
	}
	if (!Si4463::verify()) {
		UART::print_json_msg("error", "config verification");
		while (true) {}
	}
	UART::print_json_msg("info", "initialized radio");

	// Clear interrupts and fifos
	Si4463::set_state(Si4463::State::Ready);
	Si4463::clear_interrupts();
	Si4463::clear_fifos();

	// For the first 500ms, and while the button is held, turn both LEDs on;
	// this is to give a visual indication of the reset happening.
	Si4463::gpio_pin_cfg(Si4463::GPIOConfig()
	                         .gpio0(Si4463::GPIOMode::Drive_High)
	                         .gpio1(Si4463::GPIOMode::Unchanged)
	                         .gpio2(Si4463::GPIOMode::Unchanged)
	                         .gpio3(Si4463::GPIOMode::Drive_High));
	Watchdog::disable();
	_delay_ms(500);
	while (!Platform::sample_button_pin()) {
		_delay_ms(10);
	};
	Watchdog::enable();
	Si4463::gpio_pin_cfg(Si4463::GPIOConfig()
	                         .gpio0(Si4463::GPIOMode::Drive_Low)
	                         .gpio1(Si4463::GPIOMode::Unchanged)
	                         .gpio2(Si4463::GPIOMode::Unchanged)
	                         .gpio3(Si4463::GPIOMode::Drive_Low));
	Watchdog::disable();
	_delay_ms(500);
	Watchdog::enable();

	// Configure GPIO1 and GPIO2 to drive the Tx/Rx switch
	Si4463::gpio_pin_cfg(Si4463::GPIOConfig()
	                         .gpio0(Si4463::GPIOMode::Unchanged)
	                         .gpio1(Si4463::GPIOMode::Rx_State)
	                         .gpio2(Si4463::GPIOMode::Tx_State)
	                         .gpio3(Si4463::GPIOMode::Unchanged));

	// Enable µC interrupts
	sei();

	while (true) {
		// Yes, we are alive!
		wdt_reset();

		// Fetch the current time in ticks (one tick = 100µs)
		uint16_t cur_ticks = Clock::ticks();

		// Update the onboard button state
		const bool onboard_btn_debounced = btn_onboard_debounce.update(
		    cur_ticks, Platform::sample_button_pin());
		switch (btn_onboard.update(cur_ticks, onboard_btn_debounced)) {
			case OnboardButton::DoNothing:
				break;
			case OnboardButton::SendPing:
				radio_tx_buf.push("$PING\n\r");
				break;
			case OnboardButton::Reset:
				UART::print_json_msg("info", "pending reset");
				while (true) {}
				break;
		}

		// Update the doorbell state
		auto button_state =
		    btn_doorbell.update(cur_ticks, Events::get_and_reset_pulse_event(),
		                        Platform::sample_pulse_pin());
		doorbell_tx.update(cur_ticks, button_state, radio_tx_buf);

		// Send/receive data and update the LEDs
		bool has_tx_data = radio_tx_buf.level() > 0;
		radio.update(cur_ticks, radio_rx_buf, radio_tx_buf, last_can_sleep);
		bool has_rx_data = radio_rx_buf.level() > 0;
		bool in_rx = radio.known_state == Si4463::State::Rx;
		bool synced = button_state != DoorbellButton::Unknown;
		radio_leds.update_blink_pattern(has_tx_data, has_rx_data,
		                                last_can_sleep, synced, in_rx);
		radio_leds.update(cur_ticks);

		// Parse the buffer data into a message
		while (radio_rx_buf.level()) {
			uint8_t buf = radio_rx_buf.pop();
			if (buf == '$') {
				pkt_ptr = 0;
				pkt_msg[pkt_ptr++] = buf;
			}
			else if (pkt_ptr < sizeof(pkt_msg)) {
				if (buf == '\r' || buf == '\n') {
					pkt_msg[pkt_ptr] = 0;
					if (pkt_msg[0] == '$') {
						btn_onboard.no_sleep_secs =
							btn_onboard.NO_SLEEP_DUR_SEC;
						if (strcmp(pkt_msg, "$PING")) {
							radio_tx_buf.push("$PONG\n\r");
						}
						else if (strcmp(pkt_msg, "$PONG")) {
							radio_leds.left_led.set_state(
							    LEDStateMachine::BlinkQuickly, 20);
							radio_leds.right_led.set_state(
							    LEDStateMachine::BlinkQuickly, 20);
						}
						UART::print_json_msg("radio", pkt_msg);
					}
					pkt_ptr = 0;
				}
				else if (is_valid_char(buf)) {
					pkt_msg[pkt_ptr++] = buf;
				}
				else {
					pkt_ptr = 0;
				}
			}
		}

		// Handle entering sleep mode
		bool can_sleep = btn_doorbell.can_sleep() &&
		                 btn_onboard_debounce.can_sleep(cur_ticks) &&
		                 btn_onboard.can_sleep() && doorbell_tx.can_sleep() &&
		                 radio.can_sleep() && radio_leds.can_sleep();
		ATOMIC_BLOCK(ATOMIC_RESTORESTATE)
		{
			if (!can_sleep && last_can_sleep) {
				Clock::go_fast();
			}
			else if (can_sleep) {
				Clock::go_slow();
				Sleep::enter();
			}
		}
		last_can_sleep = can_sleep;
	}
}

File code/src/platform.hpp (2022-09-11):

/*
 *  AVR/Si4463 Wireless Doorbell
 *  Copyright (C) 2022  Andreas Stöckel
 *
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
 *  You should have received a copy of the GNU General Public License
 *  along with this program.  If not, see <https://www.gnu.org/licenses/>.
 */

#pragma once

#define F_CPU 14745600ULL

#include <avr/io.h>
#include <stdint.h>
#include <util/delay.h>


namespace Platform {

static inline void delay_us(double us) {
	_delay_us(us);
}

static inline void delay_ms(double ms) {
	_delay_ms(ms);
}

static inline void set_bit(volatile uint8_t &port, uint8_t pin, bool x)
{
	port = x ? (port | (1 << pin)) : (port & ~(1 << pin));
}

static inline bool get_bit(volatile uint8_t &pinreg, uint8_t pin)
{
	return (pinreg & (1 << pin)) == (1 << pin);
}

static inline bool sample_radio_irq_pin() {
	return get_bit(PIND, 2);
}

static inline bool sample_pulse_pin() {
	return get_bit(PIND, 3);
}

static inline bool sample_button_pin() {
	return get_bit(PIND, 5);
}

static inline void init_gpio() {
	// Port A: N/A

	// Port B:
	// Pin 0: CLKO
	// Pin 1: NC
	// Pin 2: Si4463 SS    O
	// Pin 3: Si4463 MOSI  O
	// Pin 4: Si4463 MISO  I
	// Pin 5: Si4463 SCK   O
	// Pin 6: N/A (XTAL1)
	// Pin 7: N/A (XTAL2)
	DDRB = 0b0010'1101;
	PORTB = 0b1101'0000;

	// Port C:
	// Pin 0: NC
	// Pin 1: NC
	// Pin 2: NC
	// Pin 3: NC
	// Pin 4: NC
	// Pin 5: NC
	// Pin 6: N/A (RESET)
	// Pin 7: NC
	DDRC = 0b0000'0000;
	PORTC = 0b1111'1111;

	// Port D:
	// Pin 0: RXD I
	// Pin 1: TXD O
	// Pin 2: Si4463 IRQ   I
	// Pin 3: PULSE I (already has a hw pull-up)
	// Pin 4: Si4463 SDN   O
	// Pin 5: BUTTON I
	// Pin 6: NC
	// Pin 7: DBG O
	DDRD  = 0b1001'0010;
	PORTD = 0b0110'0101;

	// Setup IRQs on PIND2 (INT0) and PIND3 (INT1)
	EICRA = (1 << ISC11) | (1 << ISC01);
	EIMSK = (1 << INT1) | (1 << INT0);
}

static inline void radio_reset(bool value) { set_bit(PORTD, 4, value); }

static inline void radio_select(bool value) { set_bit(PORTB, 2, value); }

static inline void radio_spi_init() {
	// Enable SPI with CHPA = 0; use F_CPU / 2
	SPCR = (1 << SPE) | (1 << MSTR);
	//SPSR = (1 << SPI2X);
}

static inline uint8_t radio_spi_send(uint8_t x)
{
	SPDR = x;
	while (!(SPSR & (1 << SPIF))) {}
	return SPDR;
}

}

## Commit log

2022-09-11 Factor out LED state machine
2022-09-11 Add Kicad project and documentation
    [drahtlos_klingel-B_Cu.gbl, drahtlos_klingel-B_Mask.gbs, drahtlos_klingel-B_Paste.gbp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]
